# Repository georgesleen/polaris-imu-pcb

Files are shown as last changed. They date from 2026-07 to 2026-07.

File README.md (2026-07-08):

# Polaris IMU PCB

## Images

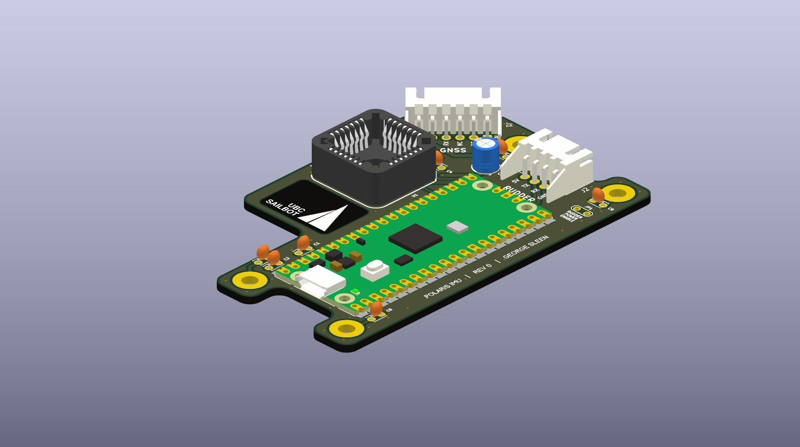
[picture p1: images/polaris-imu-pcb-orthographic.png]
Orthographic View

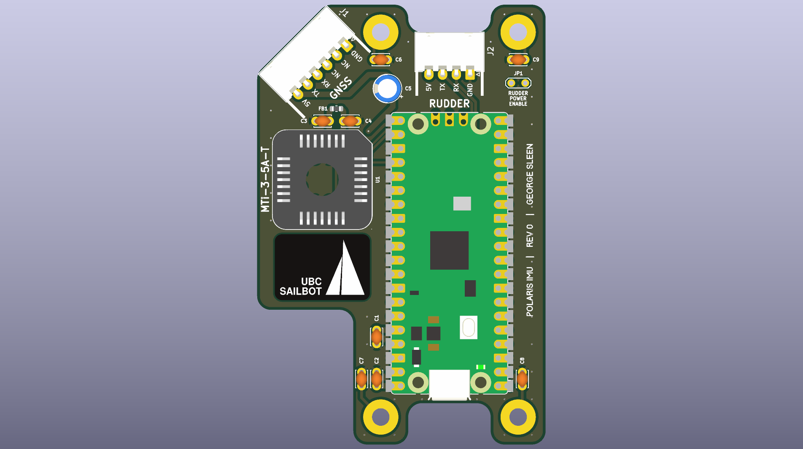
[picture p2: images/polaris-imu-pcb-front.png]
Front View

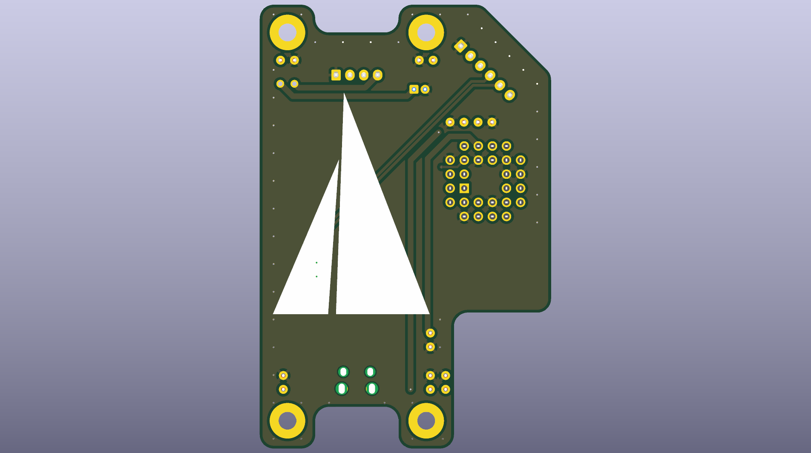
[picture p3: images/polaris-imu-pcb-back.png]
Back View


## Drawings

Schematic

PCB

## Ordering

When ordering this PCB, please tag the commit that you used and create a release on GitHub with the appropriate revision number.

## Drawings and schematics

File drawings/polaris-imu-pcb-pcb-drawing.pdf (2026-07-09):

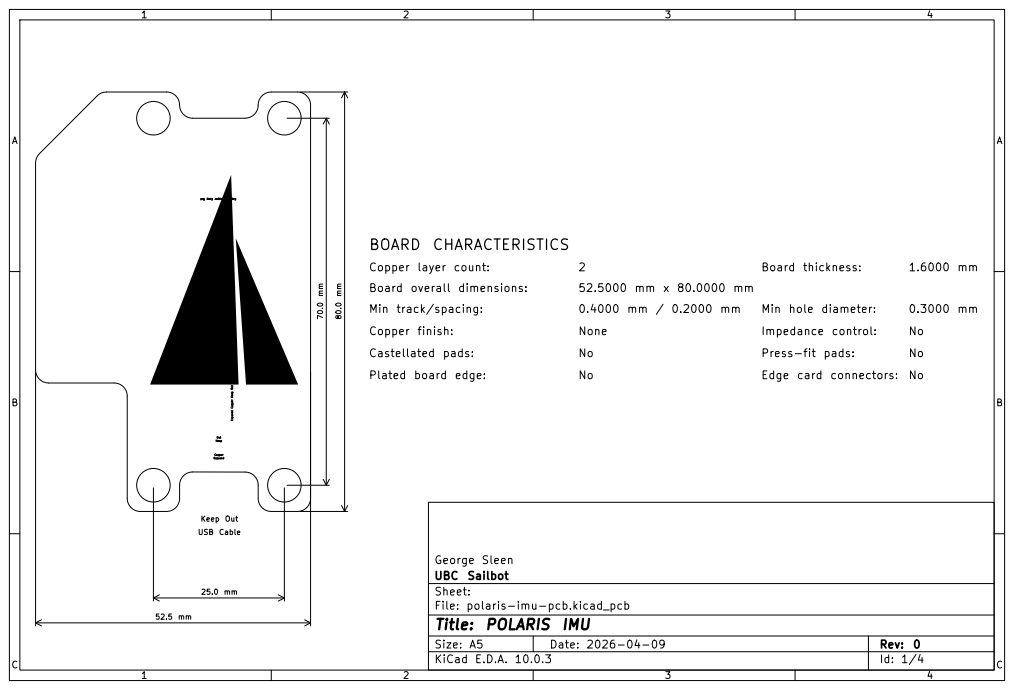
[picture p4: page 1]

52.5 mm AGND Plane
Out Keep Copper Exposed Keep Out USB CableExposed Copper Keep Out

Exposed Copper Keep Out Out Keep Copper

George Sleen
UBC Sailbot
Sheet:
File: polaris-imu-pcb.kicad_pcb
Title: POLARIS IMU

Size: A5 | Rev: 0 | C Date: 2026-04-09
KiCad E.D.A. 10.0.3 | Id: 1/4

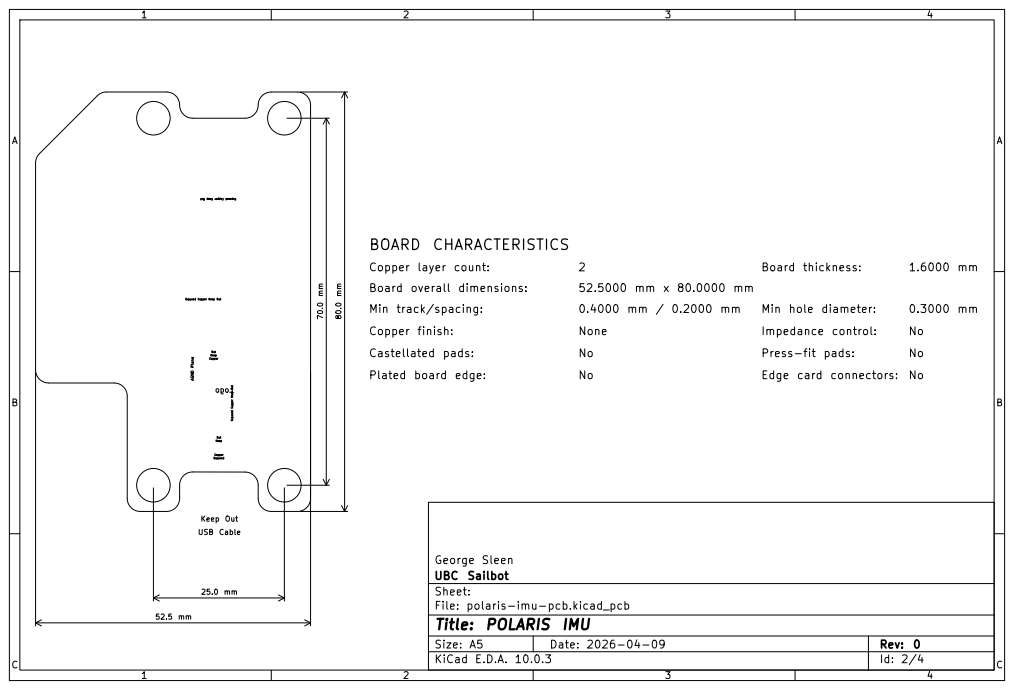
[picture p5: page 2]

52.5 mm AGND Plane
Out Keep Copper Exposed Keep Out USB CableExposed Copper Keep Out

Exposed Copper Keep Out Out Keep Copper

George Sleen
UBC Sailbot
Sheet:
File: polaris-imu-pcb.kicad_pcb
Title: POLARIS IMU

Size: A5 | Rev: 0 | C Date: 2026-04-09
KiCad E.D.A. 10.0.3 | Id: 2/4

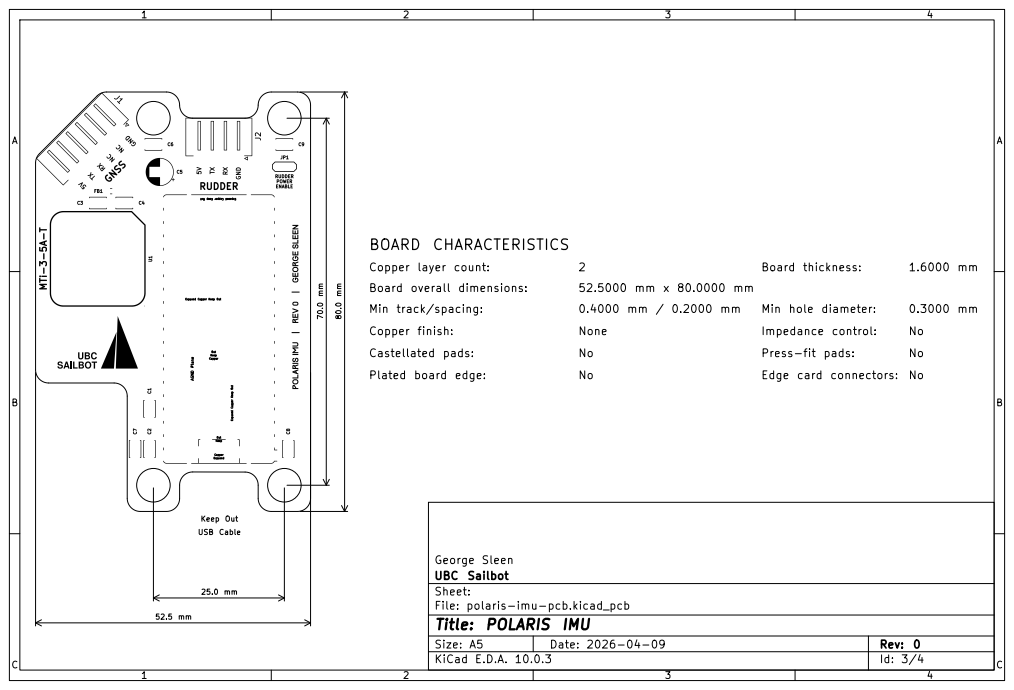
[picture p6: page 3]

52.5 mm AGND Plane
Out Keep Copper Exposed Keep Out USB CableExposed Copper Keep Out

Exposed Copper Keep Out Out Keep Copper

George Sleen
UBC Sailbot
Sheet:
File: polaris-imu-pcb.kicad_pcb
Title: POLARIS IMU

Size: A5 | Rev: 0 | C Date: 2026-04-09
KiCad E.D.A. 10.0.3 | Id: 3/4

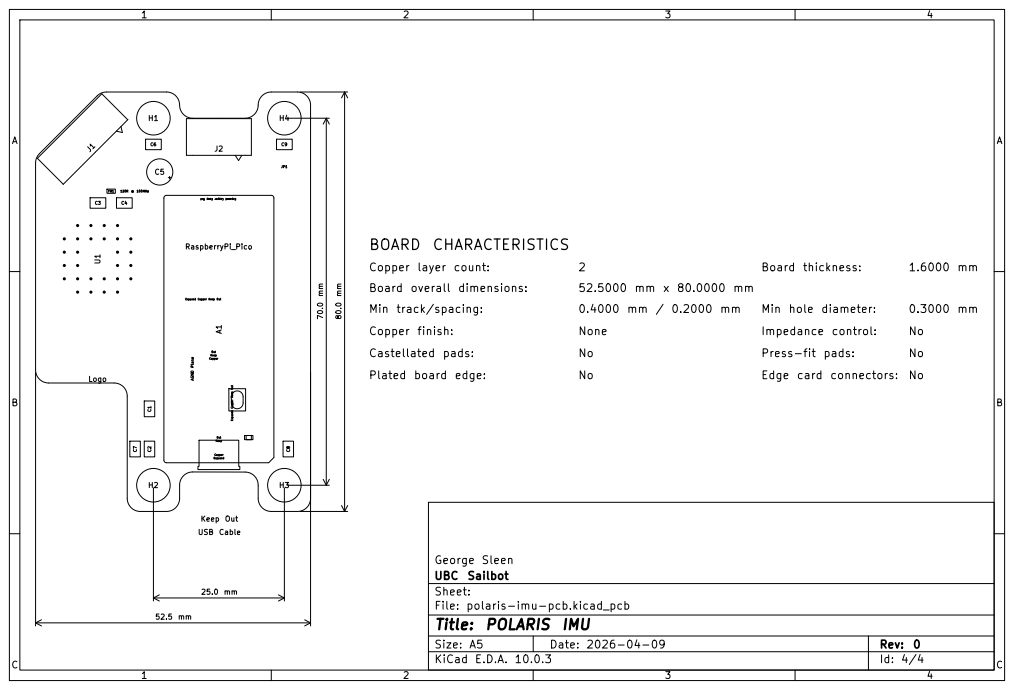
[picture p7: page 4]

52.5 mm AGND Plane
Out Keep Copper Exposed Keep Out USB CableExposed Copper Keep Out

Exposed Copper Keep Out Out Keep Copper

George Sleen
UBC Sailbot
Sheet:
File: polaris-imu-pcb.kicad_pcb
Title: POLARIS IMU

Size: A5 | Rev: 0 | C Date: 2026-04-09
KiCad E.D.A. 10.0.3 | Id: 4/4

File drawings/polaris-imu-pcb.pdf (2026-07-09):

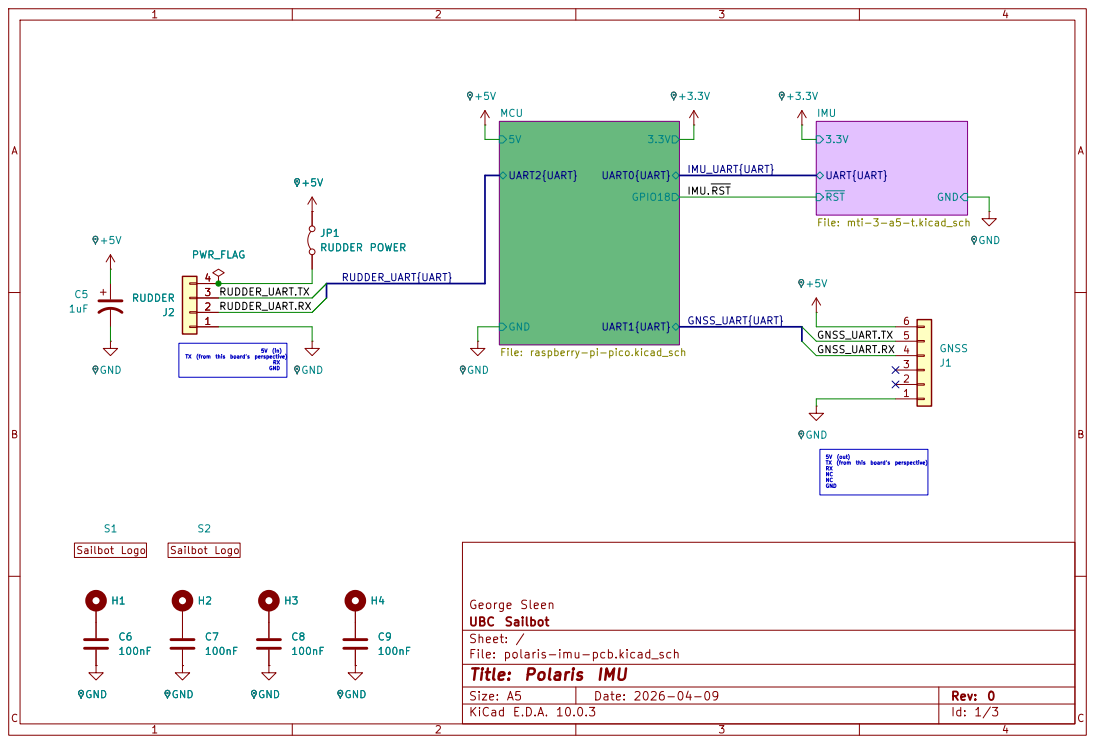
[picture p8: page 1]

5V (in) TX (from this board's perspective) RX GND

5V (out) TX (from this board's perspective) RXNCNC

George Sleen
UBC Sailbot
Sheet: /
File: polaris-imu-pcb.kicad_sch
Title: Polaris IMU

Size: A5 | Rev: 0 | C Date: 2026-04-09
KiCad E.D.A. 10.0.3 | Id: 1/3

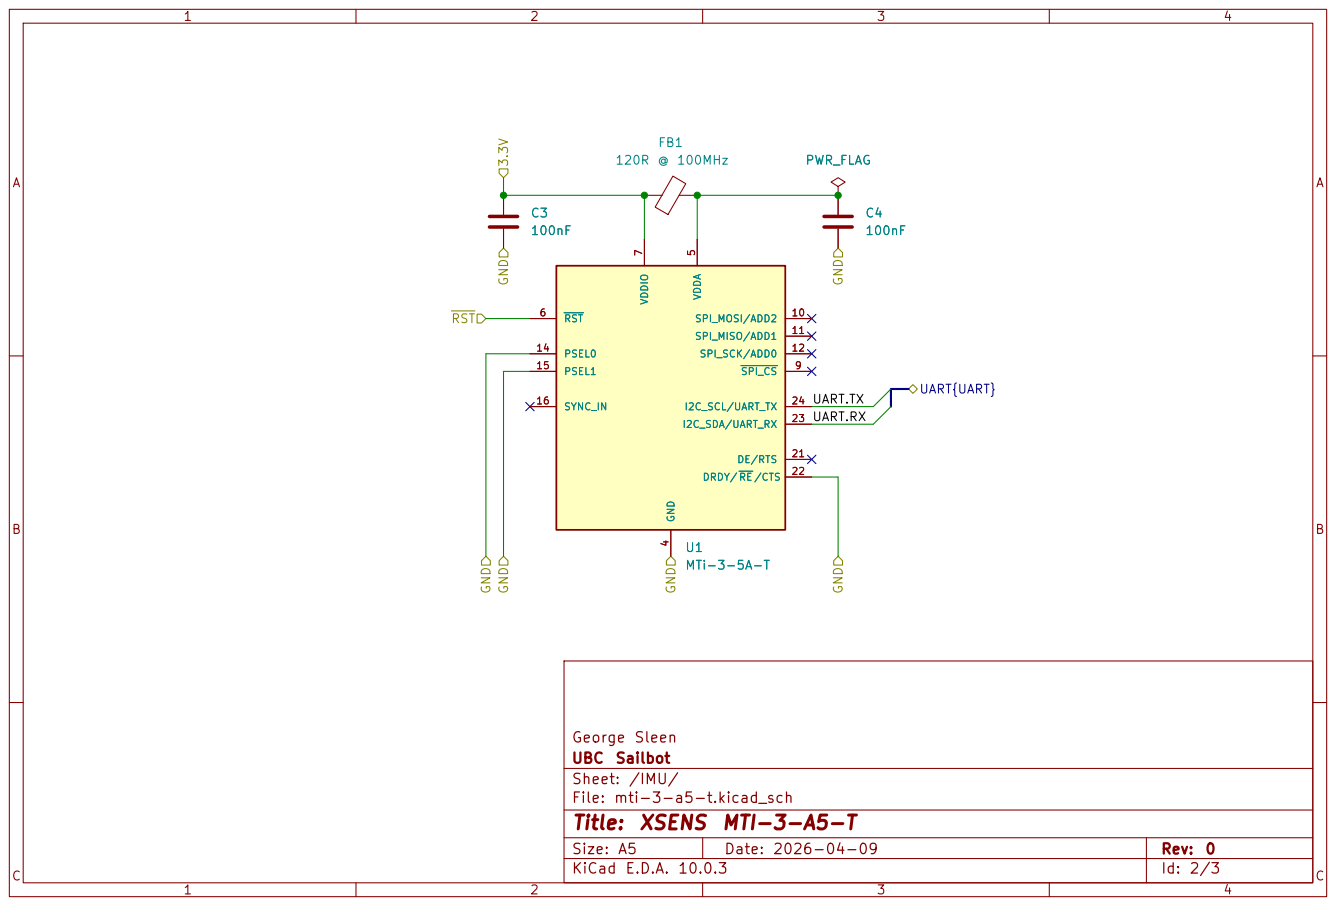
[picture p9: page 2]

Size: A5 | Rev: 0
KiCad E.D.A. 10.0.3 | Id: 2/3

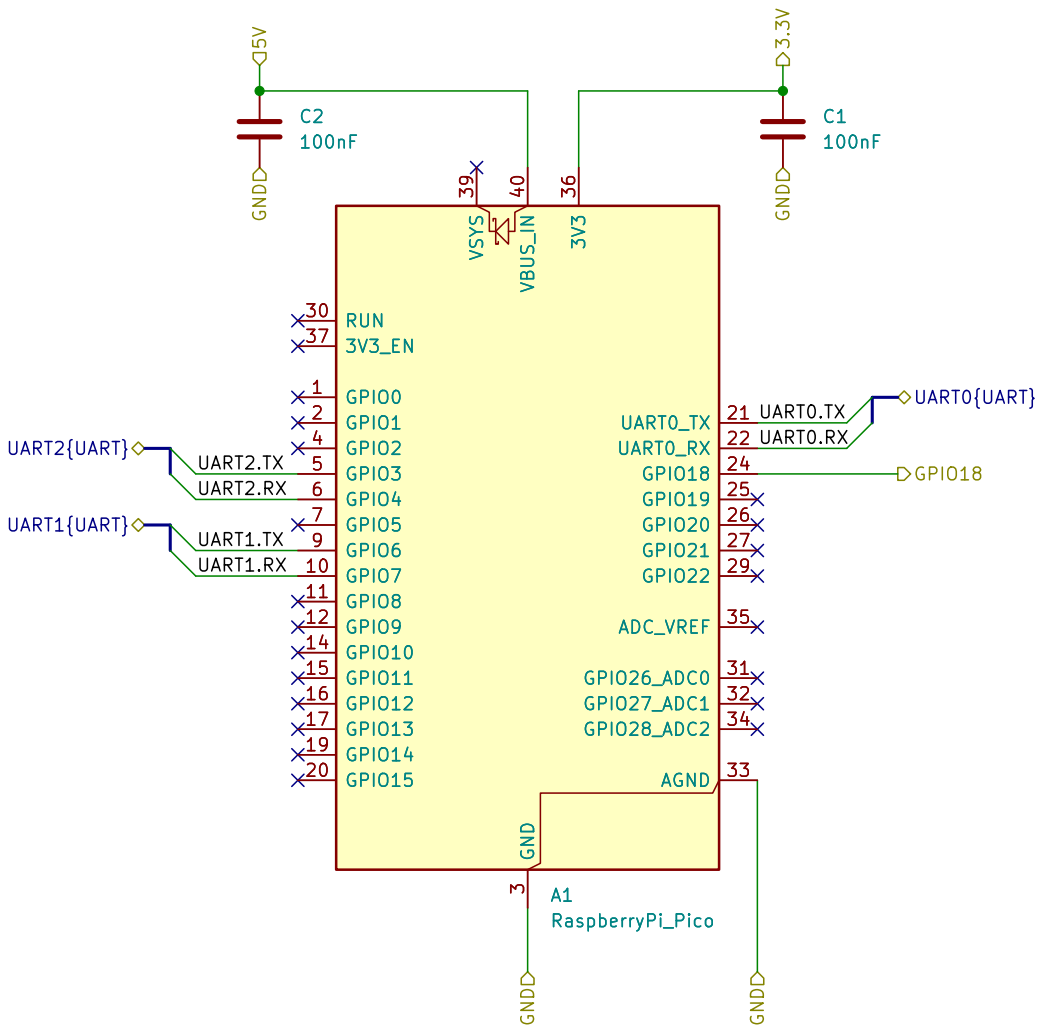
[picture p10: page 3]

George Sleen
UBC Sailbot
Sheet: /MCU/
File: raspberry-pi-pico.kicad_sch
Title: Raspberry Pi Pico

Size: A4 | Rev: 0
KiCad E.D.A. 10.0.3 | Id: 3/3

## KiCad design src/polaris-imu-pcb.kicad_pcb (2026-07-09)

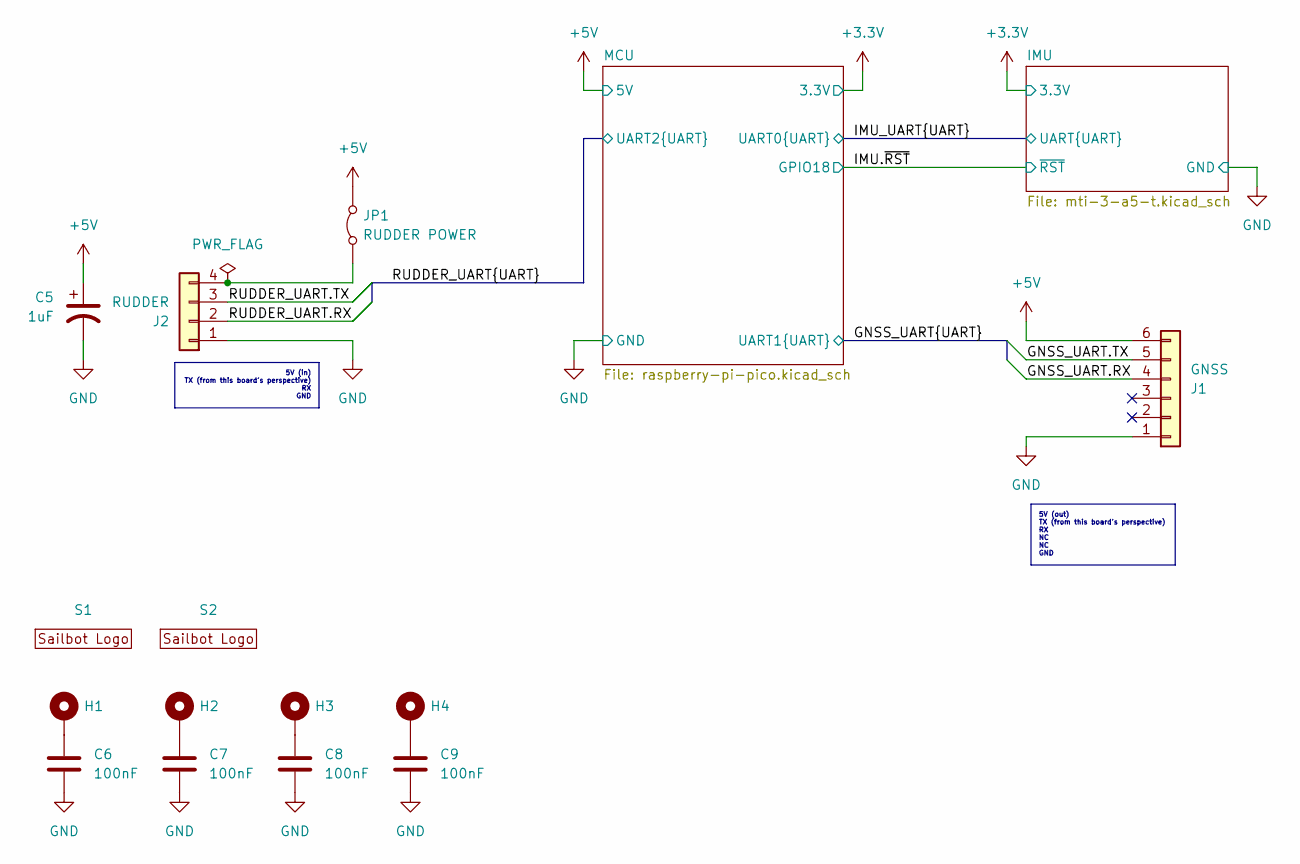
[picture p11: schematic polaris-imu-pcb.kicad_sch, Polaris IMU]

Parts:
C5: 1uF; CP_Radial_D5.0mm_P2.00mm
C6, C7, C8, C9: 100nF; C_Disc_D3.0mm_W2.0mm_P2.50mm
H1, H2, H3, H4: MountingHole_Pad; MountingHole_3.2mm_M3_Pad
J1: GNSS; JST_XH_S6B-XH-A-1_1x06_P2.50mm_Horizontal; MPN S6B-XH-A-1(LF)(SN); LCSC ID C265069
J2: RUDDER; JST_XH_S4B-XH-A-1_1x04_P2.50mm_Horizontal; MPN S4B-XH-A-1(LF)(SN); LCSC ID C163037
JP1: RUDDER POWER; TestPoint_2Pads_Pitch2.54mm_Drill0.8mm
S1: Logo; UBC_Sailbot_Logo_Silk
S2: Logo; UBC_Sailbot_Logo_Huge

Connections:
/+5V: C5.1, J1.6, JP1.2 (B); also elsewhere on the board
/GND: C5.2, C6.2, C7.2, C8.2, C9.2, J1.1, J2.1; also elsewhere on the board
/GNSS_UART.RX: J1.4; also elsewhere on the board
/GNSS_UART.TX: J1.5; also elsewhere on the board
/RUDDER_UART.RX: J2.2; also elsewhere on the board
/RUDDER_UART.TX: J2.3; also elsewhere on the board
unnamed: C6.1, H1.1 (1_1)
unnamed: C7.1, H2.1 (1_1)
unnamed: C8.1, H3.1 (1_1)
unnamed: C9.1, H4.1 (1_1)
unnamed: J2.4, JP1.1 (A)

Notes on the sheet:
5V (out) TX (from this board's perspective) RX NC NC GND
5V (in) TX (from this board's perspective) RX GND

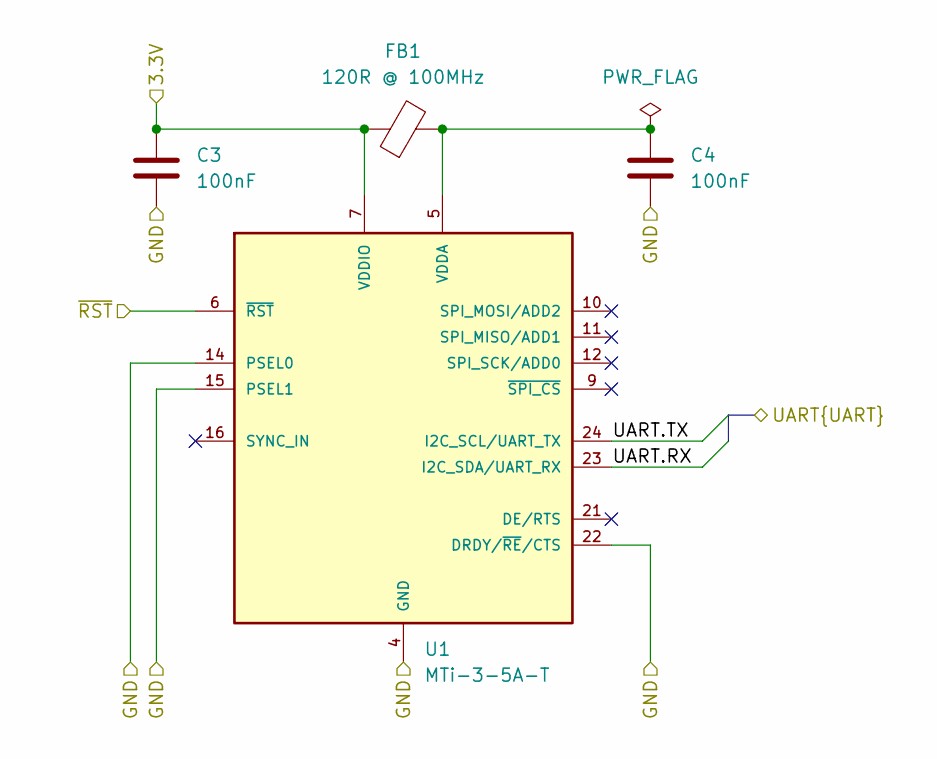
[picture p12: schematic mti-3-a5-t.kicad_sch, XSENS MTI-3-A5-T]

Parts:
C3, C4: 100nF; C_Disc_D3.0mm_W2.0mm_P2.50mm
FB1: 120R @ 100MHz; L_0603_1608Metric; MPN BLM18KG121TN1D; LCSC ID C85831
U1: MTi-3-5A-T; PLCC-28-AT; MPN MTi-3-5A-T

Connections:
/+3.3V: C3.1, FB1.1, U1.7 (VDDIO); also elsewhere on the board
/GND: C3.2, C4.2, U1.4 (GND), U1.8 (GND), U1.13 (GND), U1.14 (PSEL0), U1.15 (PSEL1), U1.22 (DRDY/~RE/CTS), U1.25 (GND); also elsewhere on the board
/IMU.~RST: U1.6 (~RST); also elsewhere on the board
/IMU_UART.RX: U1.23 (I2C_SDA/UART_RX); also elsewhere on the board
/IMU_UART.TX: U1.24 (I2C_SCL/UART_TX); also elsewhere on the board
unnamed: C4.1, FB1.2, U1.5 (VDDA)

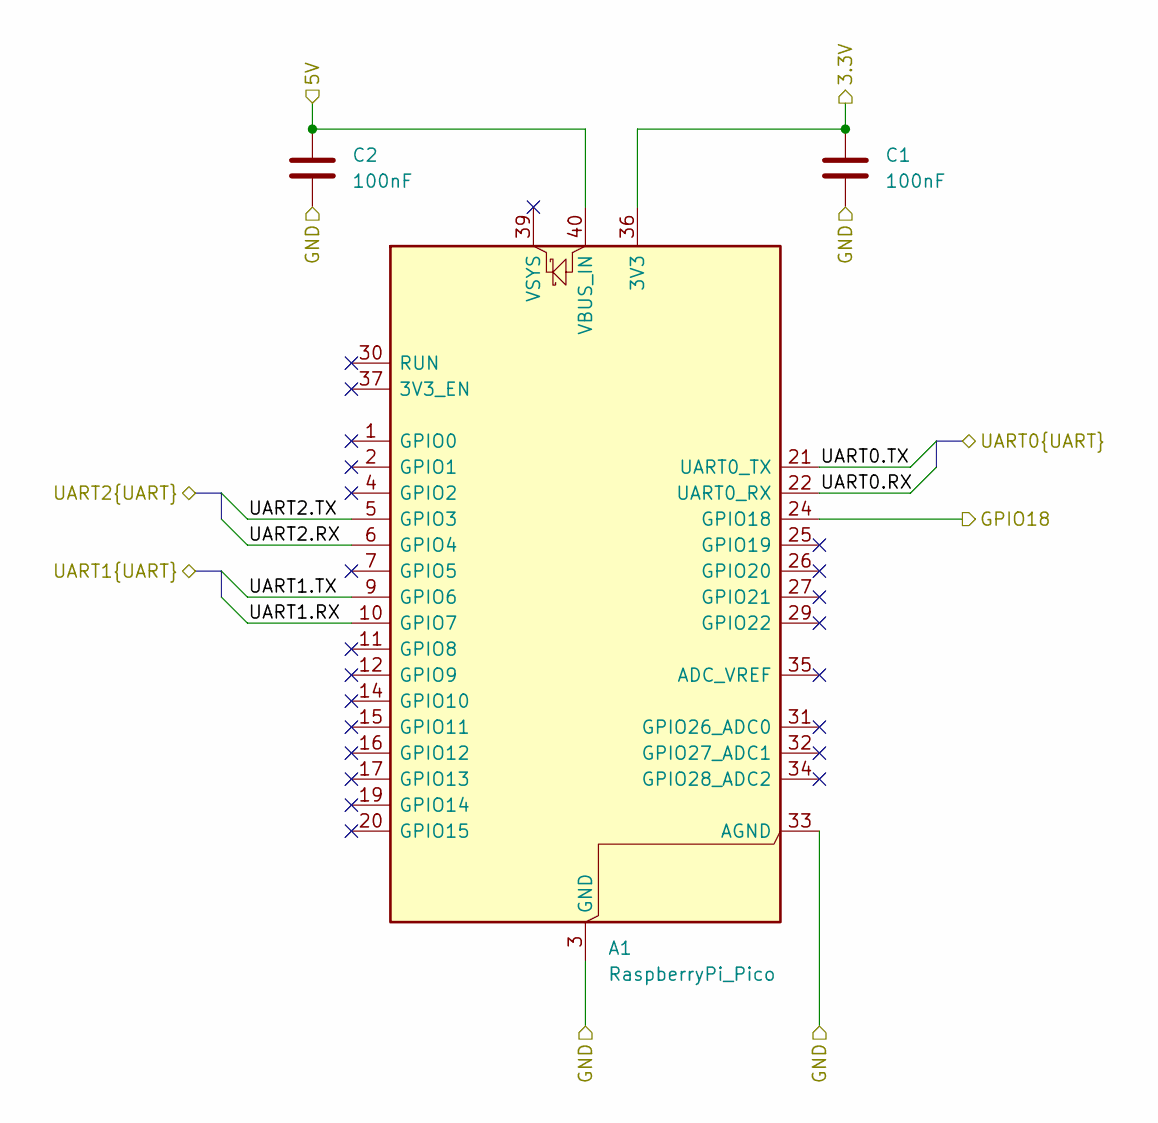
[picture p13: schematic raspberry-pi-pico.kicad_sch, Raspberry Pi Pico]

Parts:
A1: RaspberryPi_Pico; RaspberryPi_Pico_Common_SMD
C1, C2: 100nF; C_Disc_D3.0mm_W2.0mm_P2.50mm

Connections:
/+3.3V: A1.36 (3V3), C1.1; also elsewhere on the board
/+5V: A1.40 (VBUS_IN), C2.1; also elsewhere on the board
/GND: A1.3 (GND), A1.8 (GND), A1.13 (GND), A1.18 (GND), A1.23 (GND), A1.28 (GND), A1.33 (AGND), A1.38 (GND), C1.2, C2.2; also elsewhere on the board
/GNSS_UART.RX: A1.10 (GPIO7); also elsewhere on the board
/GNSS_UART.TX: A1.9 (GPIO6); also elsewhere on the board
/IMU.~RST: A1.24 (GPIO18); also elsewhere on the board
/IMU_UART.RX: A1.22 (UART0_RX); also elsewhere on the board
/IMU_UART.TX: A1.21 (UART0_TX); also elsewhere on the board
/RUDDER_UART.RX: A1.6 (GPIO4); also elsewhere on the board
/RUDDER_UART.TX: A1.5 (GPIO3); also elsewhere on the board

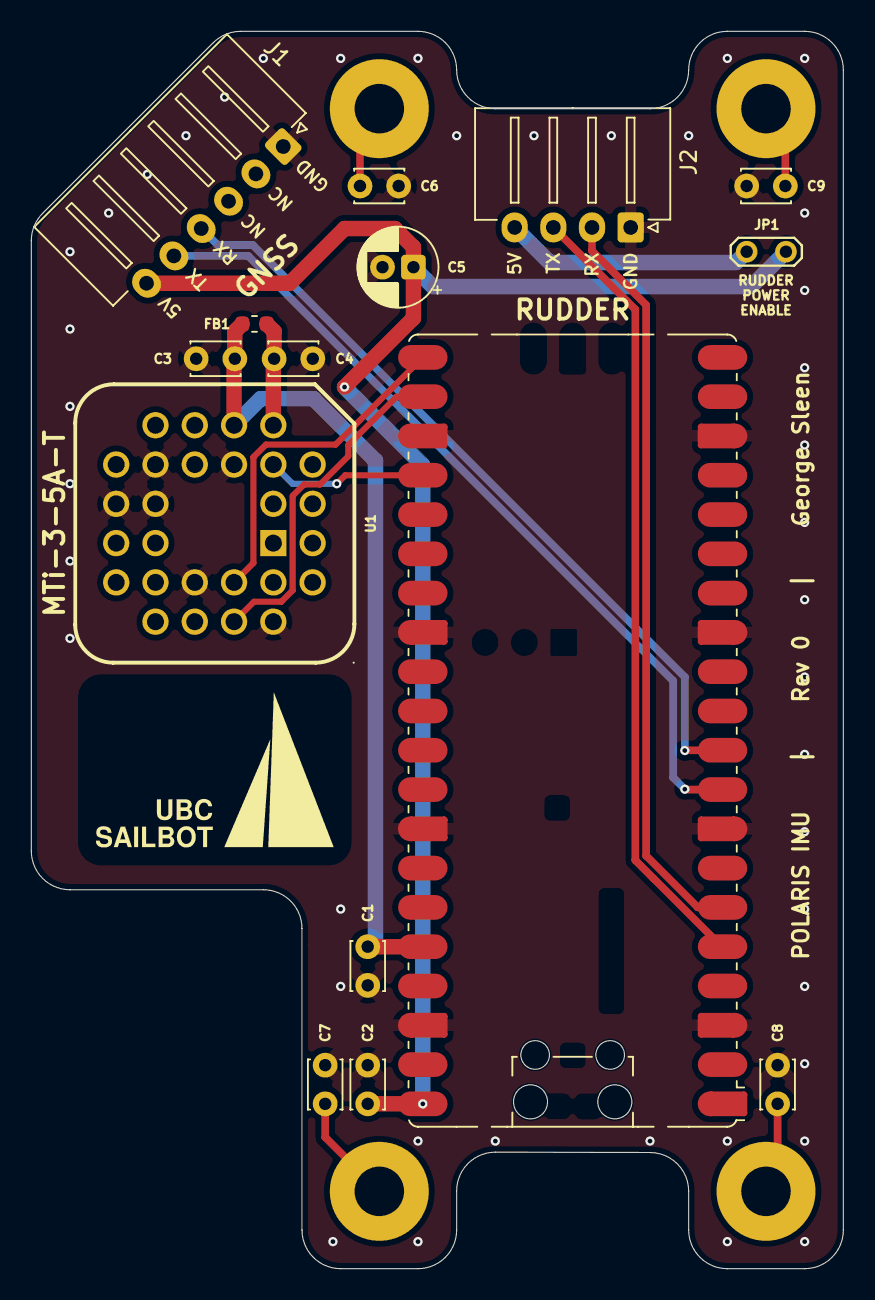
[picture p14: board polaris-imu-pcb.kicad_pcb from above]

Board: 2 copper layers, 52.5 x 80.0 mm, 21 parts (1 on the bottom side), 16 nets.

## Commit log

2026-07-08 Initial draft for Rev 0
    [debug-probe.kicad_sch, mech-connections.kicad_sch, mti-3-a5-t.kicad_sch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]
2026-07-08 Add other production files
    [polaris-imu-pcb.step]
2026-07-08 Add board characteristics
    [polaris-imu-pcb.kicad_pcb, polaris-imu-pcb.step]
2026-07-08 First draft of rev 0
    [polaris-imu-pcb.kicad_pcb, polaris-imu-pcb.step]
2026-07-09 Small updates for rev0
    [polaris-imu-pcb.kicad_pcb, polaris-imu-pcb.kicad_sch, polaris-imu-pcb.step]
2026-07-09 Fix silkscreen on sailbot badge
    [polaris-imu-pcb.kicad_pcb]
